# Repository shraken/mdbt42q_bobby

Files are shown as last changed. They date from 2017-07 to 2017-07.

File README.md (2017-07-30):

# mdbt42q_bobby

A simple break-out board in KiCad EDA for developing Nordic nRF52 BLE projects using the MDBT42 module.  Includes external 32.768 kHz watch crystal and components for internal DC/DC operation.  Breaks out 18 pins from the MDBT42Q module for easy prototyping.  

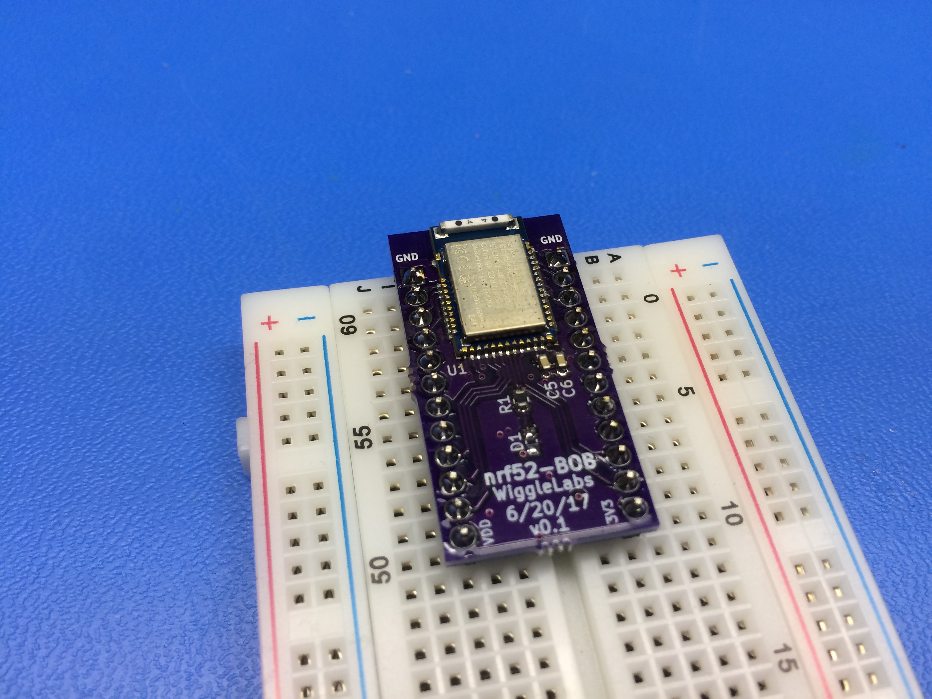
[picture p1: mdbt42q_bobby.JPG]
mdbt42q-bobby


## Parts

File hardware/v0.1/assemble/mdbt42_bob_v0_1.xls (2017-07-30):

MDBT42_BOB_V0.1
Mouser # | Mfr. # | Manufacturer | Customer # | Description | RoHS | Lifecycle | Order Qty. | Price (USD) | Ext.: (USD)
595-TLV70033DDCR | TLV70033DDCR | Texas Instruments |  | LDO Voltage Regulators 200mA Low IQ LDO Reg for Portables | RoHS Compliant |  | 1 | $0.44 | $0.44
963-CBMF1608T100K | CBMF1608T100K | Taiyo Yuden |  | Fixed Inductors 0603 10uH 468mOhms +/-10% 115mA | RoHS Compliant |  | 1 | $0.23 | $0.23
963-HK160815NJ-T | HK160815NJ-T | Taiyo Yuden |  | Fixed Inductors 0603 15nH 320mOhms +/-5%Tol 300mA HiQ | RoHS Compliant |  | 1 | $0.11 | $0.11
815-ABS07LR32.76-61T | ABS07-LR-32.768kHz-6-1-T | ABRACON |  | Crystals 32.768kHz 6pF 10ppm | RoHS Compliant |  | 1 | $0.98 | $0.98
81-GCM188R71E105KA4D | GCM188R71E105KA64D | Murata |  | Multilayer Ceramic Capacitors MLCC - SMD/SMT 0603 1uF 25volts X7R 10% | RoHS Compliant |  | 1 | $0.24 | $0.24
81-GRM39X104K50D | GRM188R71H104KA93D | Murata |  | Multilayer Ceramic Capacitors MLCC - SMD/SMT 0603 0.1uF 50volts X7R 10% | RoHS Compliant |  | 3 | $0.10 | $0.30
71-CRCW0603-4.7K-E3 | CRCW06034K70FKEA | Vishay |  | Thick Film Resistors - SMD 1/10watt 4.7Kohms 1% | RoHS Compliant By Exemption |  | 1 | $0.10 | $0.10
859-LTST-C191KRKT | LTST-C191KRKT | Lite-On |  | Standard LEDs - SMD Red Clear 631nm | RoHS Compliant |  | 1 | $0.30 | $0.30
81-GCM21BR71A106KE2L | GCM21BR71A106KE22L | Murata |  | Multilayer Ceramic Capacitors MLCC - SMD/SMT 0805 10uF 10volts X7R 10% | RoHS Compliant |  | 1 | $0.49 | $0.49
603-RC0201FR-0712KL | RC0201FR-0712KL | Yageo |  | Thick Film Resistors - SMD 12K OHM 1% | RoHS Compliant |  | 1 | $0.10 | $0.10
81-GRM1885C1H9R0DA1D | GRM1885C1H9R0DA01D | Murata |  | Multilayer Ceramic Capacitors MLCC - SMD/SMT 0603 9.0pF 50volts C0G +/-0.5pF | RoHS Compliant |  | 2 | $0.10 | $0.20

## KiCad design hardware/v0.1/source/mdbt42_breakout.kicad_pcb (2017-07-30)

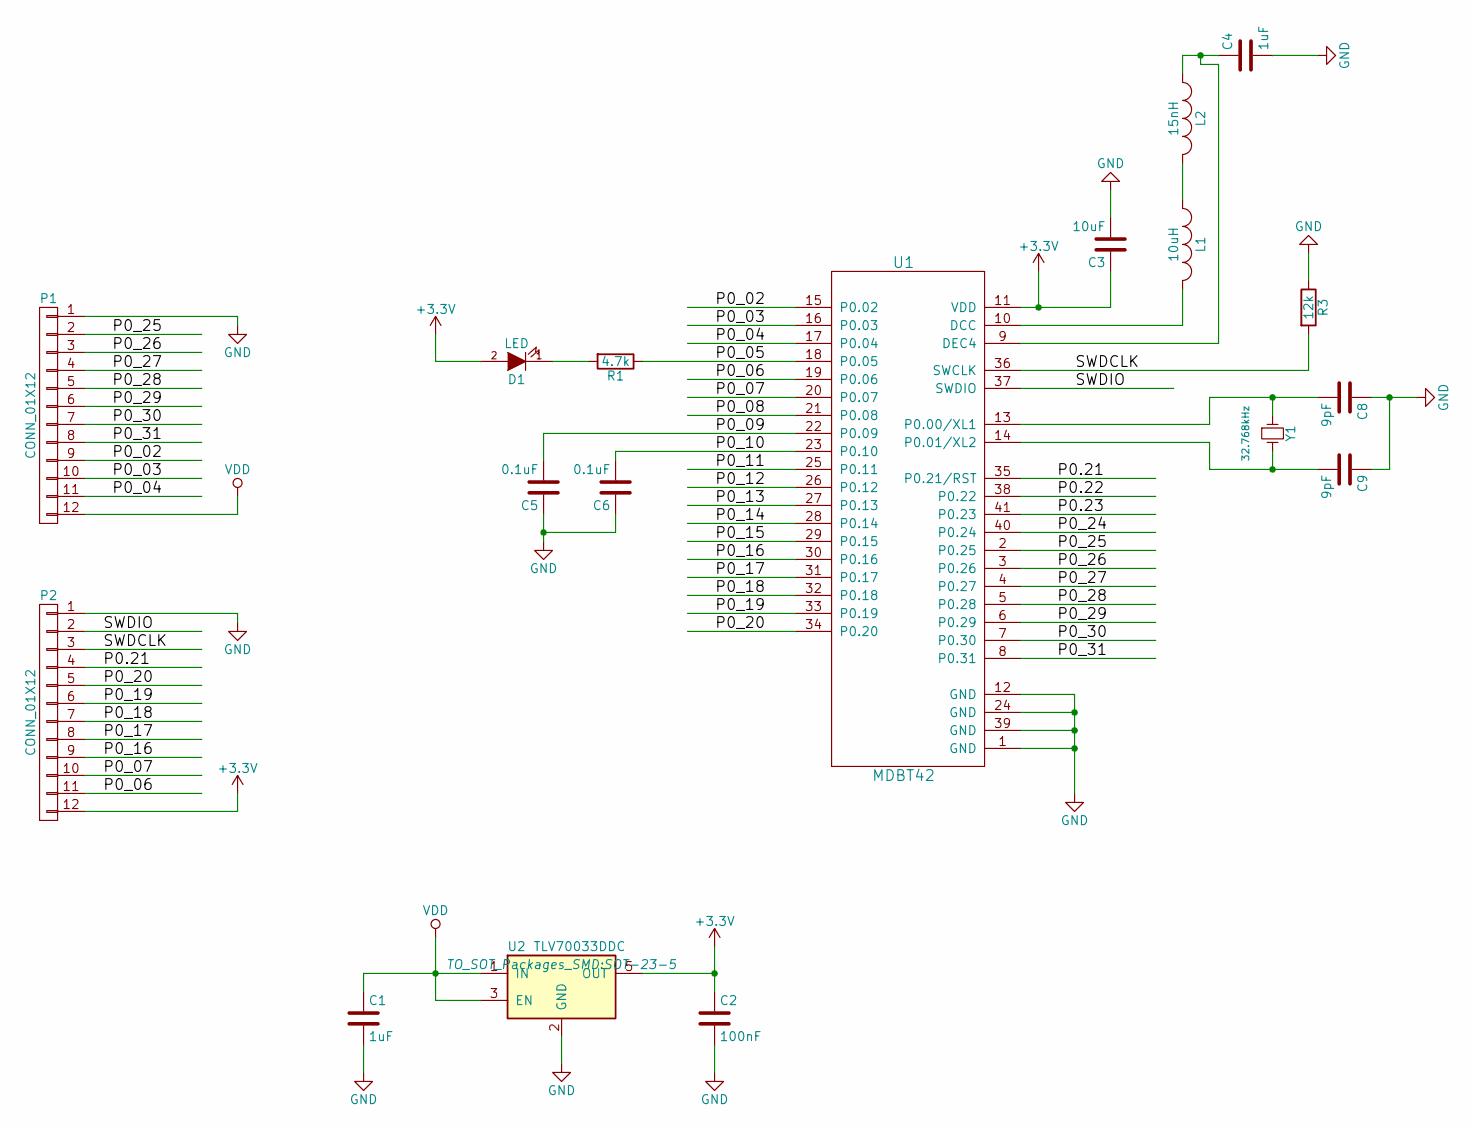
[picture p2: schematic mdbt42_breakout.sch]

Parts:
C1, C4: 1uF; C_0603_HandSoldering
C2: 100nF; C_0603_HandSoldering
C3: 10uF; C_0805_HandSoldering
C5, C6: 0.1uF; C_0603_HandSoldering
C8, C9: 9pF; C_0603_HandSoldering
D1: LED; LED_0603
L1: 10uH; C_0603_HandSoldering
L2: 15nH; C_0603_HandSoldering
P1, P2: CONN_01X12; Pin_Header_Straight_1x12
R1: 4.7k; R_0603_HandSoldering
R3: 12k; R_0603_HandSoldering
U1: MDBT42
U2: TLV70033DDC; SOT-23-5
Y1: 32.768kHz; ABS07-LR-32.768kHz-6-1-T

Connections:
+3V3: C2.1, C3.1, D1.2 (A), P2.12, U1.11 (VDD), U2.5 (OUT)
/P0.21: P2.4, U1.35 (P0.21/RST)
/P0.22: U1.38 (P0.22)
/P0.23: U1.41 (P0.23)
/P0_02: P1.9, U1.15 (P0.02)
/P0_03: P1.10, U1.16 (P0.03)
/P0_04: P1.11, U1.17 (P0.04)
/P0_05: R1.1, U1.18 (P0.05)
/P0_06: P2.11, U1.19 (P0.06)
/P0_07: P2.10, U1.20 (P0.07)
/P0_08: U1.21 (P0.08)
/P0_09: C5.2, U1.22 (P0.09)
/P0_10: C6.2, U1.23 (P0.10)
/P0_11: U1.25 (P0.11)
/P0_12: U1.26 (P0.12)
/P0_13: U1.27 (P0.13)
/P0_14: U1.28 (P0.14)
/P0_15: U1.29 (P0.15)
/P0_16: P2.9, U1.30 (P0.16)
/P0_17: P2.8, U1.31 (P0.17)
/P0_18: P2.7, U1.32 (P0.18)
/P0_19: P2.6, U1.33 (P0.19)
/P0_20: P2.5, U1.34 (P0.20)
/P0_24: U1.40 (P0.24)
/P0_25: P1.2, U1.2 (P0.25)
/P0_26: P1.3, U1.3 (P0.26)
/P0_27: P1.4, U1.4 (P0.27)
/P0_28: P1.5, U1.5 (P0.28)
/P0_29: P1.6, U1.6 (P0.29)
/P0_30: P1.7, U1.7 (P0.30)
/P0_31: P1.8, U1.8 (P0.31)
/SWDCLK: P2.3, R3.2, U1.36 (SWCLK)
/SWDIO: P2.2, U1.37 (SWDIO)
GND: C1.2, C2.2, C3.2, C4.2, C5.1, C6.1, C8.1, C9.1, P1.1, P2.1, R3.1, U1.1 (GND), U1.12 (GND), U1.24 (GND), U1.39 (GND), U2.2 (GND)
unnamed: C4.1, L2.1, U1.9 (DEC4)
unnamed: C8.2, U1.13 (P0.00/XL1), Y1.1
unnamed: C9.2, U1.14 (P0.01/XL2), Y1.2
unnamed: D1.1 (K), R1.2
unnamed: L1.1, L2.2
unnamed: L1.2, U1.10 (DCC)
VDD: C1.1, P1.12, U2.1 (IN), U2.3 (EN)

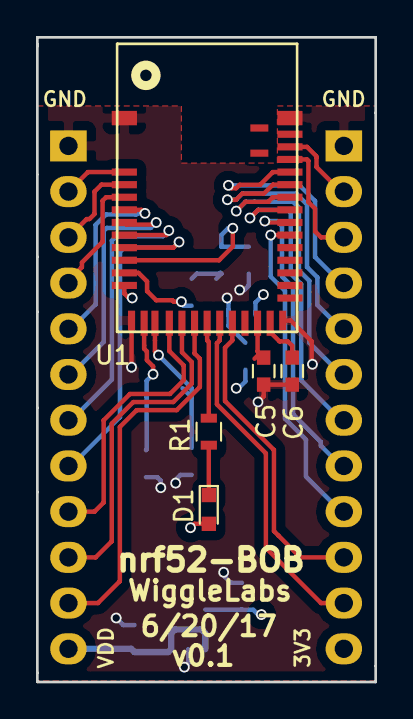
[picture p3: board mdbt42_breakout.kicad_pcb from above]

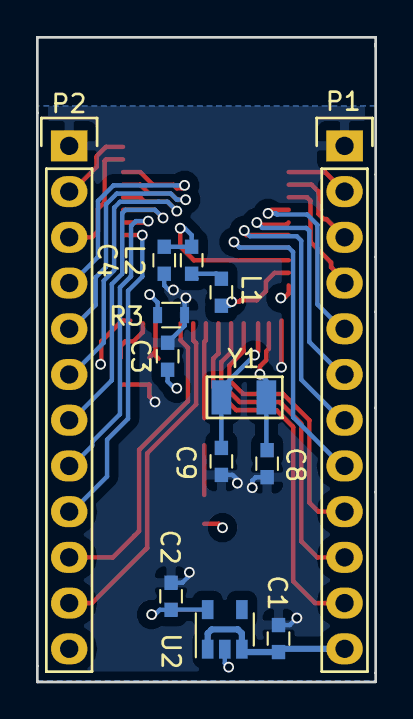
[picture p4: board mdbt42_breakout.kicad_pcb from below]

Board: 4 copper layers, 18.8 x 35.8 mm, 18 parts (13 on the bottom side), 32 nets.

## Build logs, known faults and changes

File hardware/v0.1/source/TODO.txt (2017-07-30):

v0.1:
v0.2:
	1. expand pad 12 and 24 on MDBT42Q on part U1.
